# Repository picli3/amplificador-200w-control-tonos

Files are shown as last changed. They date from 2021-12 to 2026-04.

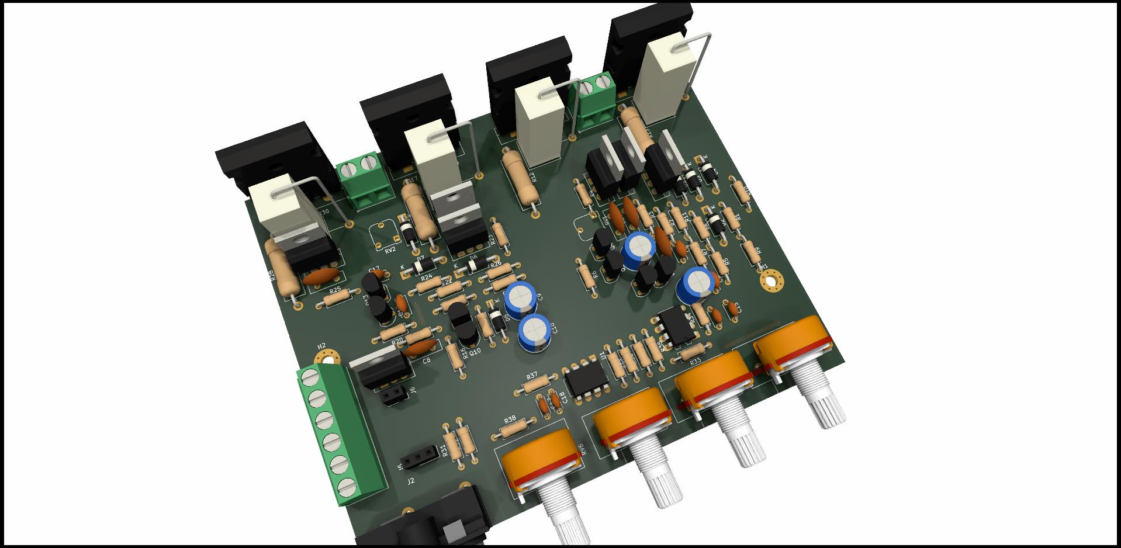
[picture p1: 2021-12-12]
doc/amplificador_200w_estereo.jpg

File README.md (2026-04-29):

# amplificador-200w-control-tonos

Diseño de amplificador de audio con control de tonos, pensado para integrar etapa de potencia y acondicionamiento de señal en una sola solución de hardware.

## Qué incluye
- esquemáticos o archivos de diseño en KiCad
- PCB o documentación asociada
- base reutilizable para análisis, fabricación o mejora del proyecto

## Propósito general
Este repositorio busca concentrar el diseño de hardware del proyecto en un formato editable y reutilizable, facilitando pruebas, documentación y futuras iteraciones del circuito.

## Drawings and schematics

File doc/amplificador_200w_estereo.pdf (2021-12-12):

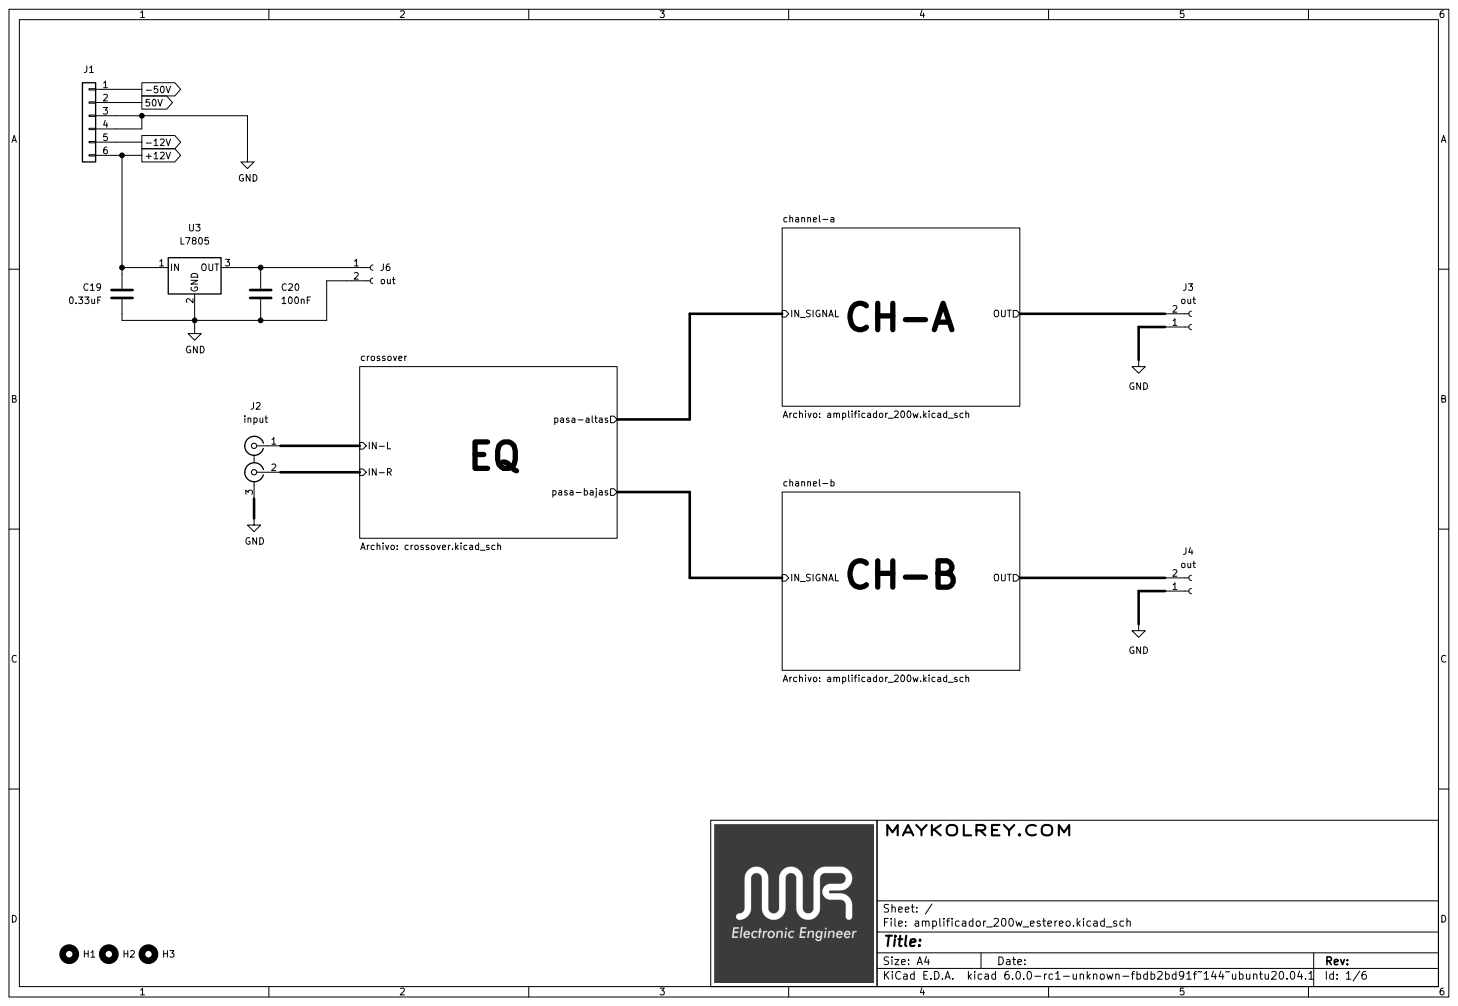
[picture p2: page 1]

File: amplificador_200w_estereo.kicad_sch Sheet: / MAYKOLREY.COM

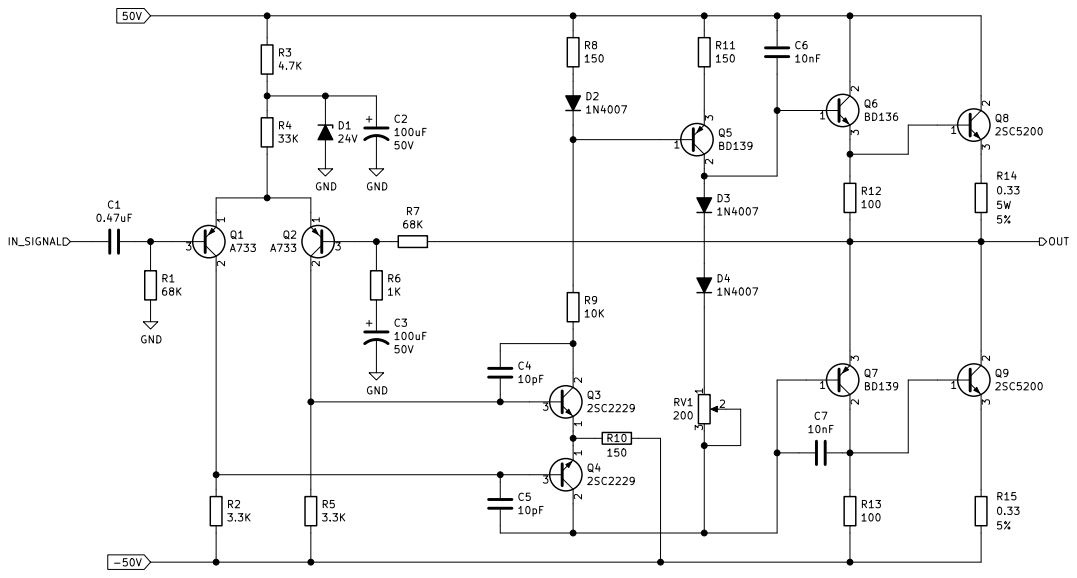
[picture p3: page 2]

File: amplificador_200w.kicad_sch Sheet: /channel-a/ https://maykolrey.com

Id: 2/6 Title: Amplificador Zener 100W

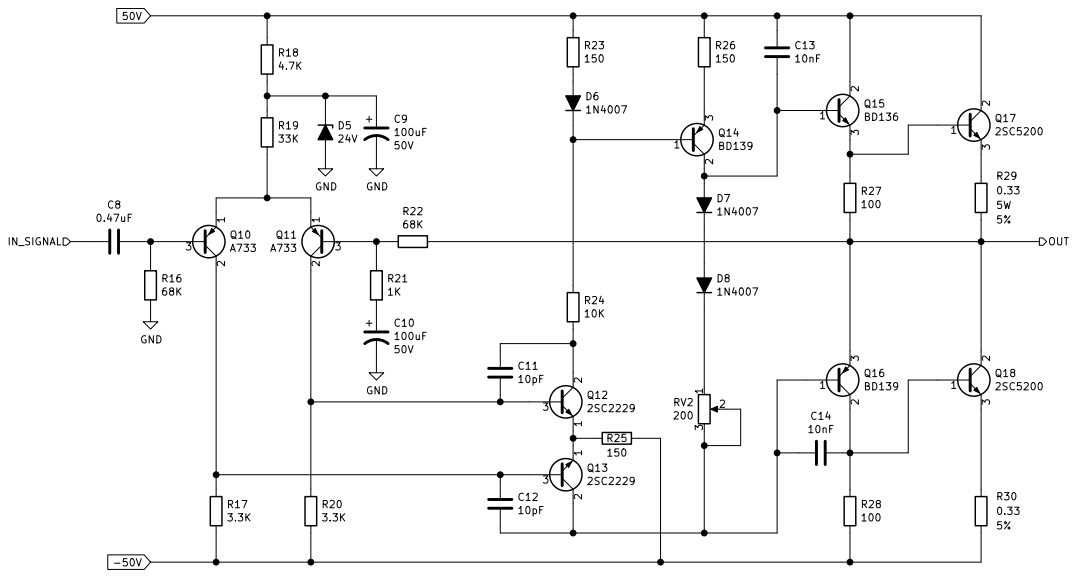
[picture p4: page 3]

File: amplificador_200w.kicad_sch Sheet: /channel-b/ https://maykolrey.com

Id: 3/6 Title: Amplificador Zener 100W

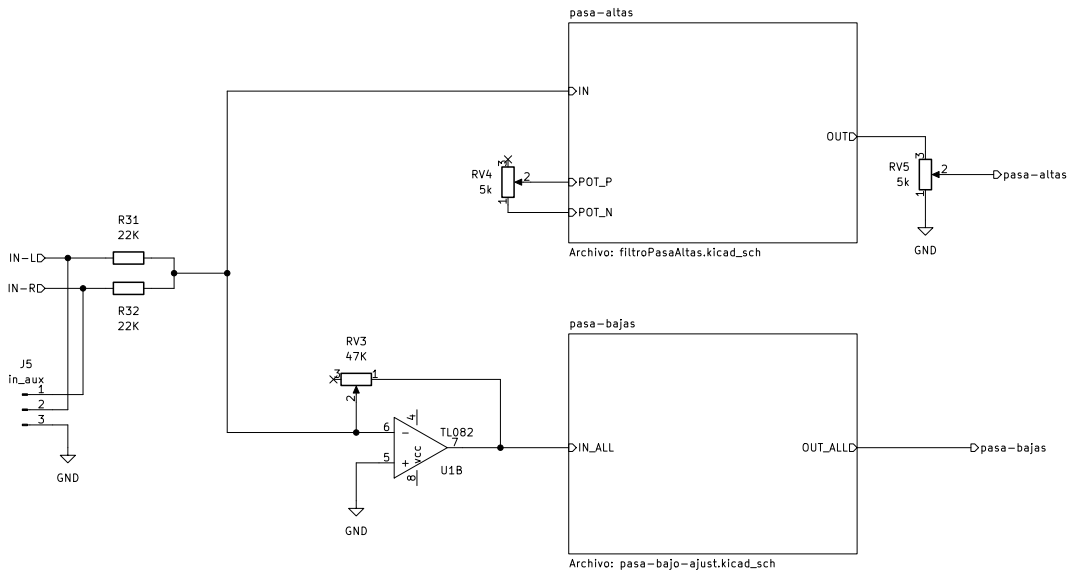
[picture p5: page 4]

pasa-altas Archivo: filtroPasaAltas.kicad_sch
Archivo: pasa-bajo-ajust.kicad_sch POT_N

File: crossover.kicad_sch Sheet: /crossover/ MAYKOLREY.COM

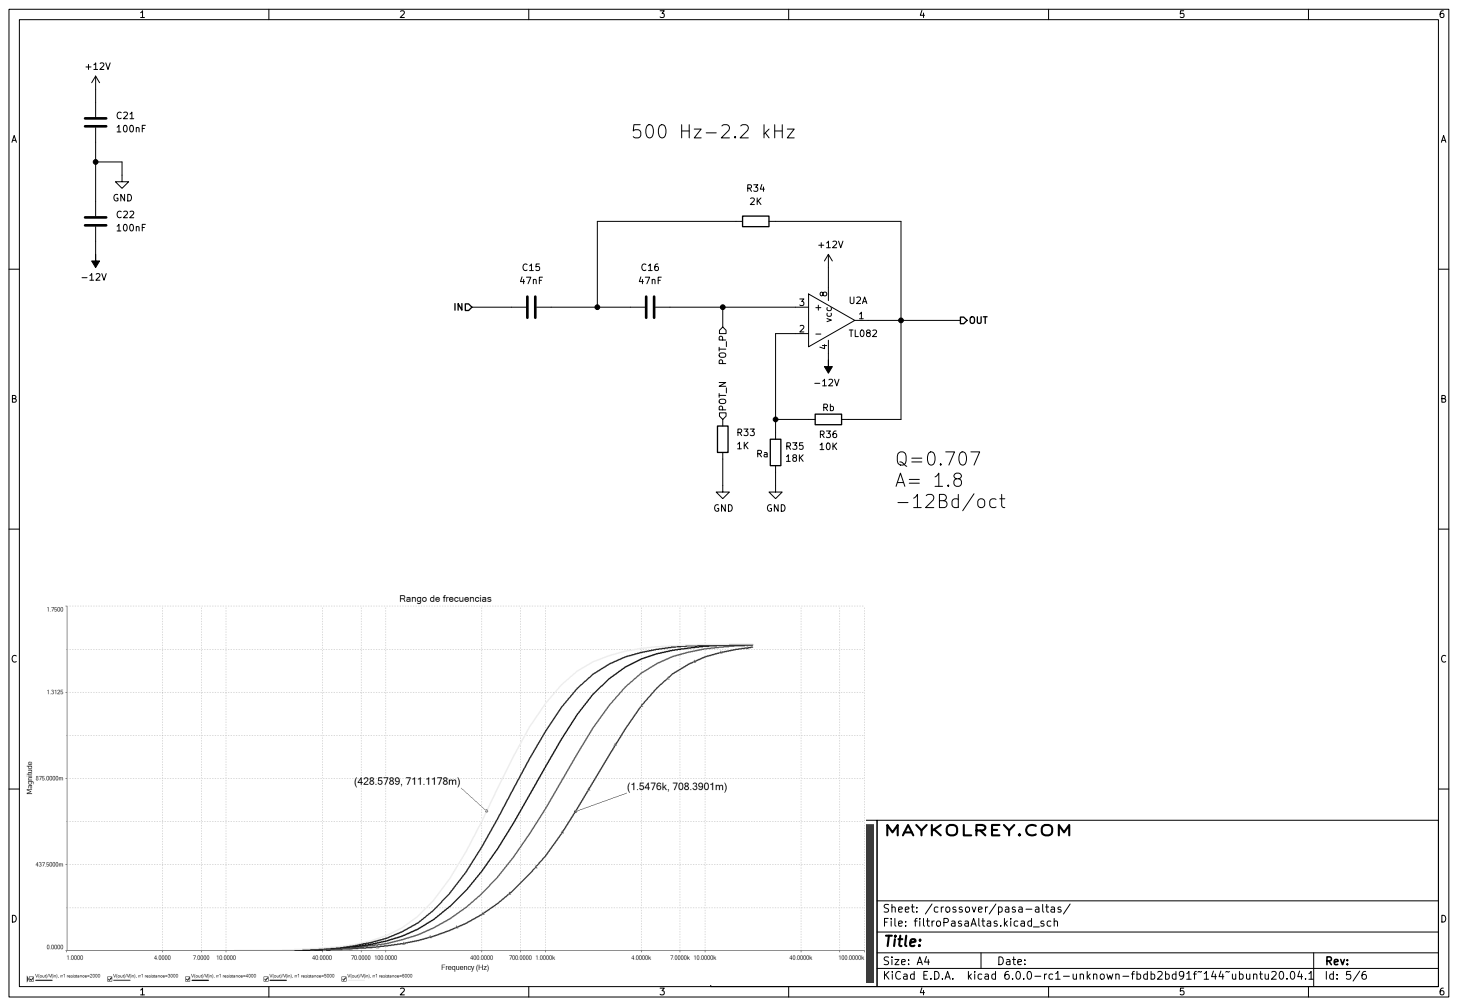
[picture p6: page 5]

Sheet: /crossover/pasa-altas/
File: filtroPasaAltas.kicad_sch
Id: 5/6 Title:

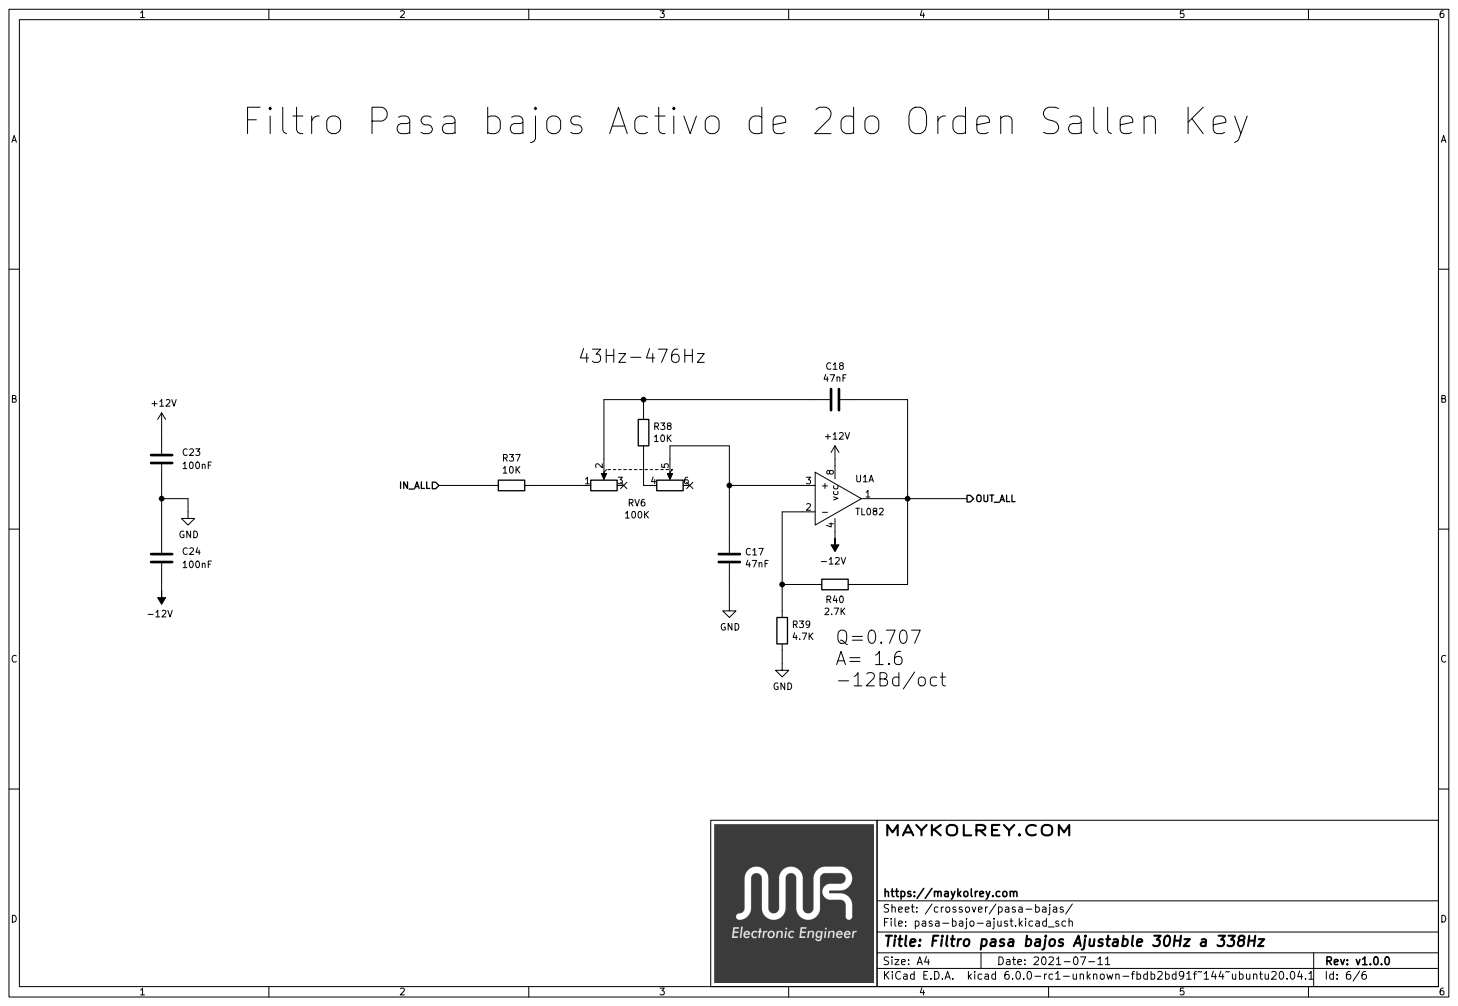
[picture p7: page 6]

Filtro Pasa bajos Activo de 2do Orden Sallen Key

https://maykolrey.com
Sheet: /crossover/pasa-bajas/
File: pasa-bajo-ajust.kicad_sch
Id: 6/6 Title: Filtro pasa bajos Ajustable 30Hz a 338Hz

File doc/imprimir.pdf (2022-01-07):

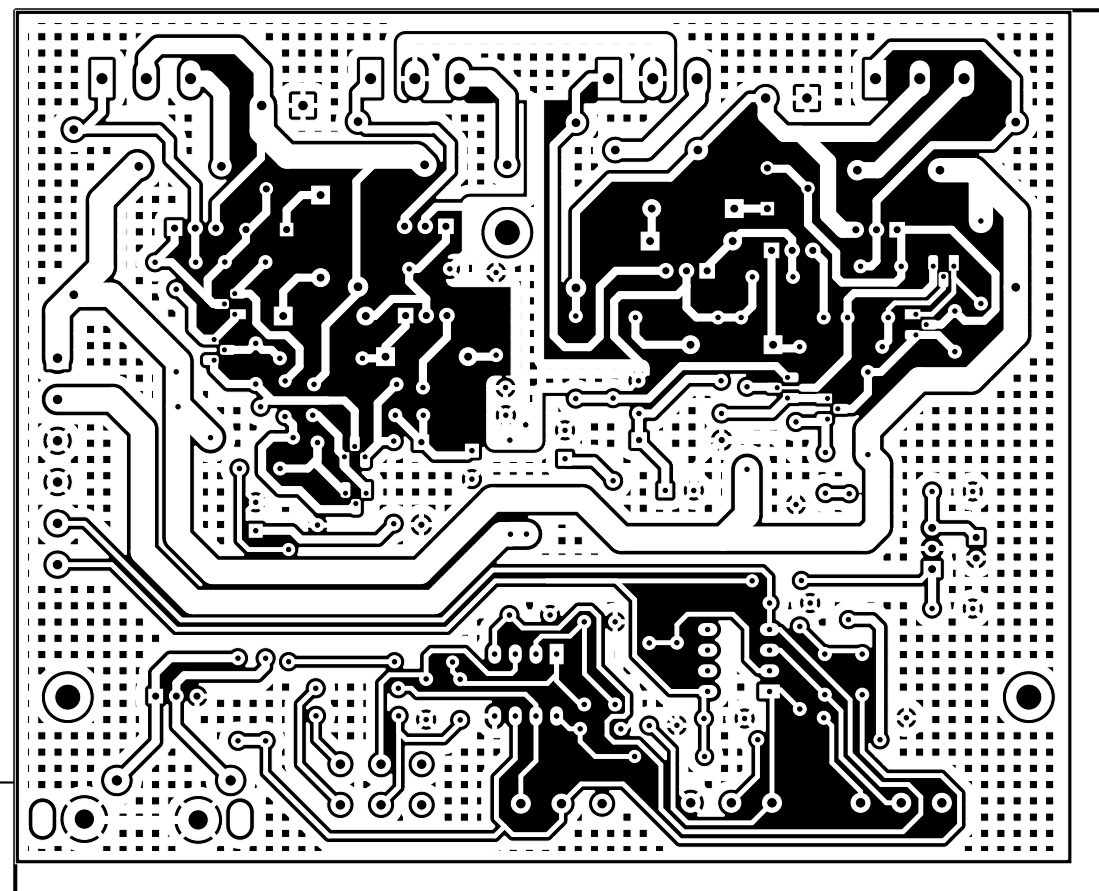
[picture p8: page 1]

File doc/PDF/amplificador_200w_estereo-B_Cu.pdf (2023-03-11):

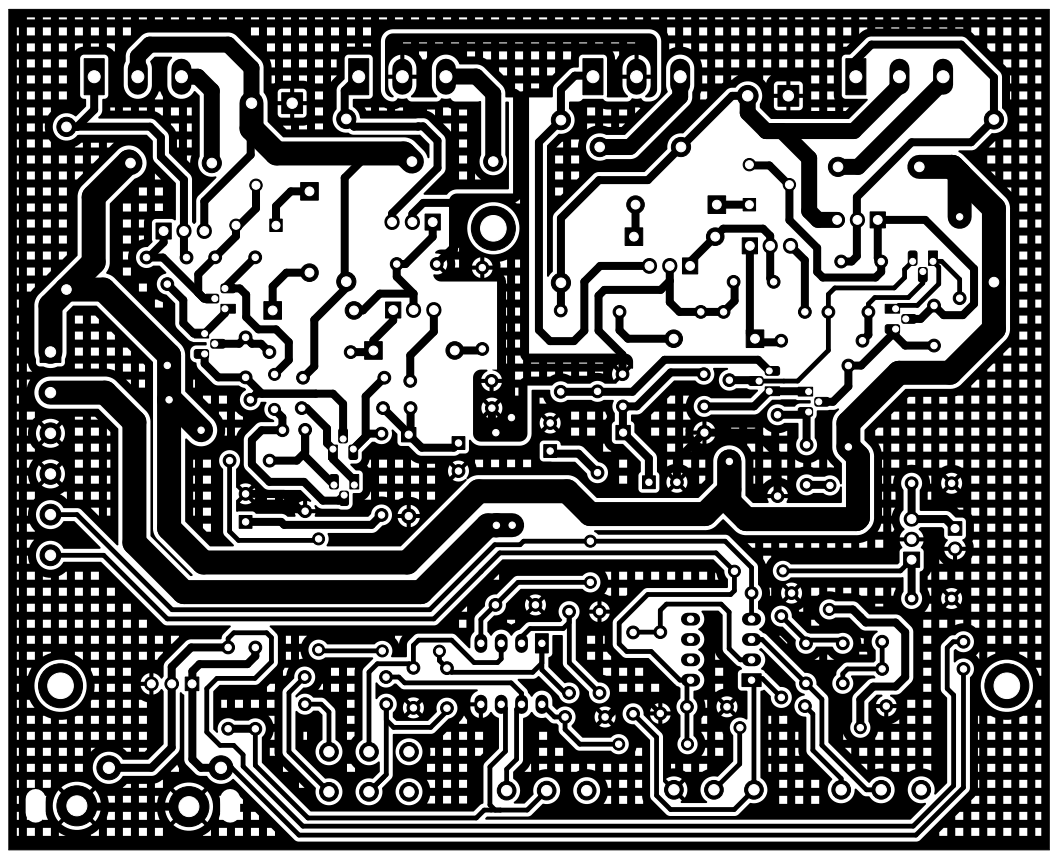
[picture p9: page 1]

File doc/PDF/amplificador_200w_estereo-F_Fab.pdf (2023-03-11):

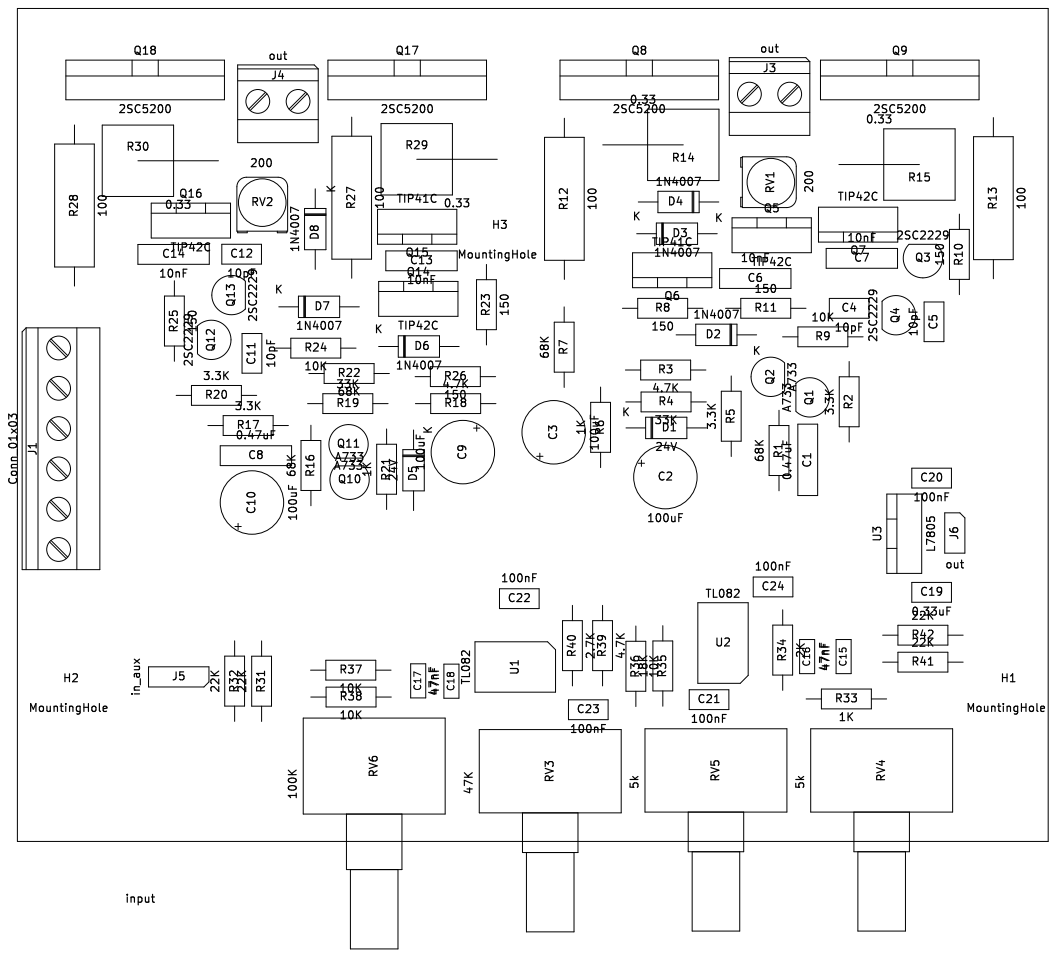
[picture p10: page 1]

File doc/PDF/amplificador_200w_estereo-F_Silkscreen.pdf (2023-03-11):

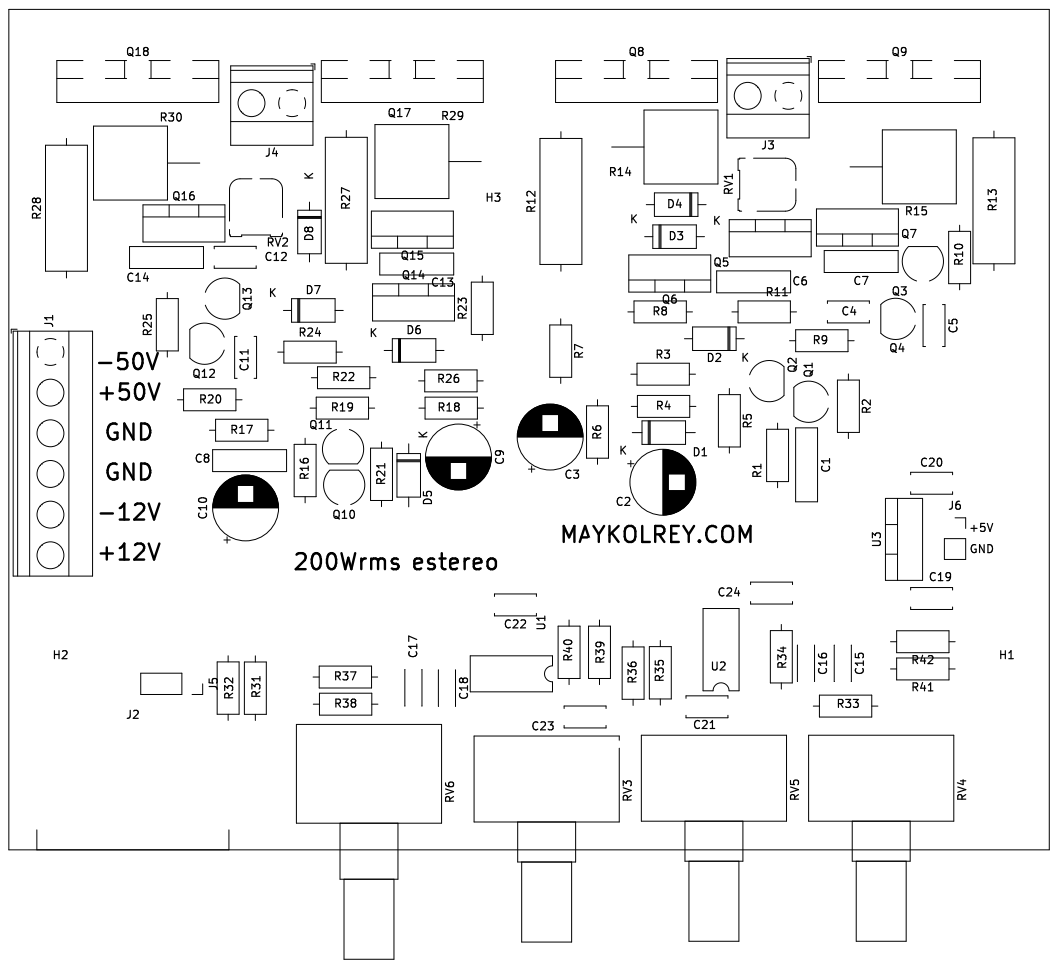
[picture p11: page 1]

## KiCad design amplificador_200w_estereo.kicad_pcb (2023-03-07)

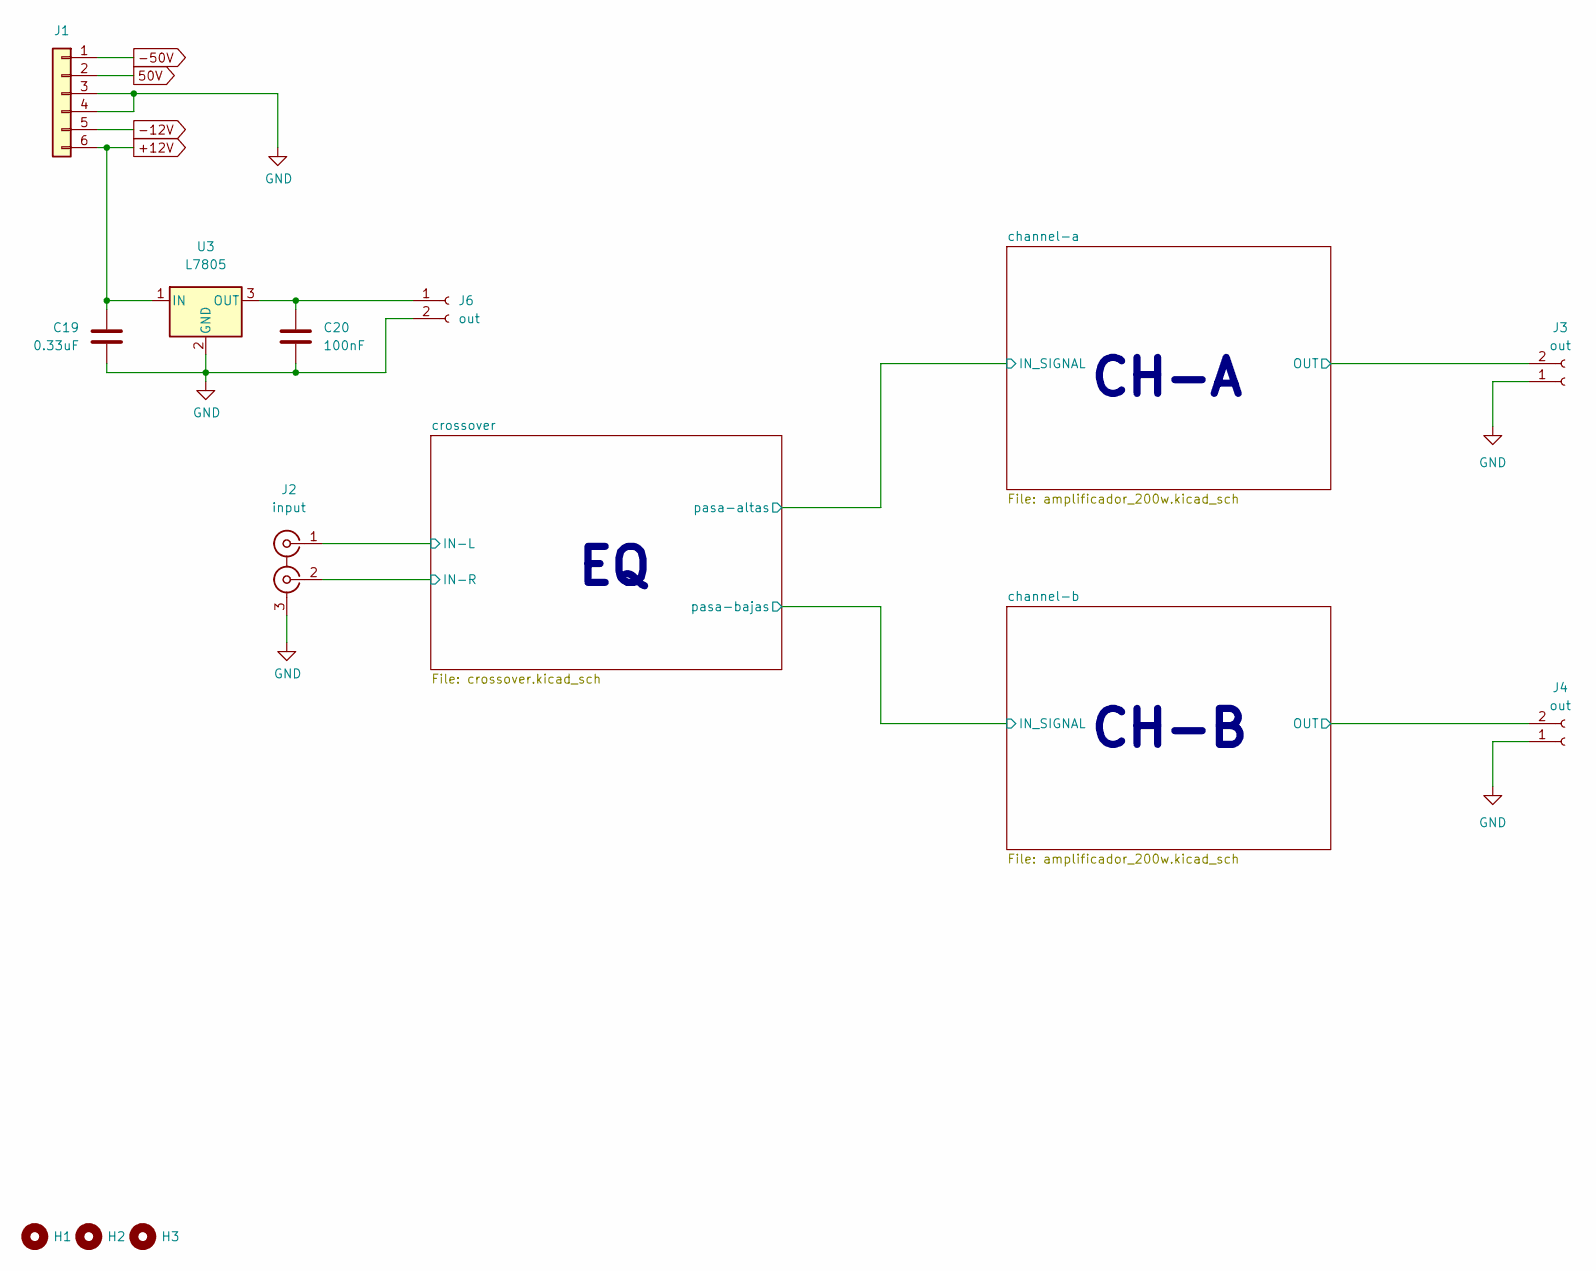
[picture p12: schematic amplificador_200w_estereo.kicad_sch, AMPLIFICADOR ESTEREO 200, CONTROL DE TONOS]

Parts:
C19: 0.33uF; C_Disc_D5.0mm_W2.5mm_P5.00mm
C20: 100nF; C_Disc_D5.0mm_W2.5mm_P5.00mm
H1, H2, H3: MountingHole; MountingHole_3.2mm_M3_ISO14580_Pad
J1: Conn_01x03; TerminalBlock_Phoenix_MKDS-1,5-6-5.08_1x06_P5.08mm_Horizont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
J2: input; CUI_RCJ-21XX
J3, J4, J6: out; TerminalBlock_Phoenix_MKDS-1,5-2-5.08_1x02_P5.08mm_Horizont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
U3: L7805; TO-220-3_Vertical

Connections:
50V: J1.2; also elsewhere on the board
+12V: C19.1, J1.6, U3.1 (IN); also elsewhere on the board
-12V: J1.5; also elsewhere on the board
-50V: J1.1; also elsewhere on the board
/channel-b/OUT: J4.2; also elsewhere on the board
GND: C19.2, C20.2, J1.3, J1.4, J2.3 (EXT), J3.1, J4.1, J6.2, U3.2 (GND); also elsewhere on the board
unnamed 34: C20.1, J6.1, U3.3 (OUT); also elsewhere on the board

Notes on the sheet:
CH-B
CH-A

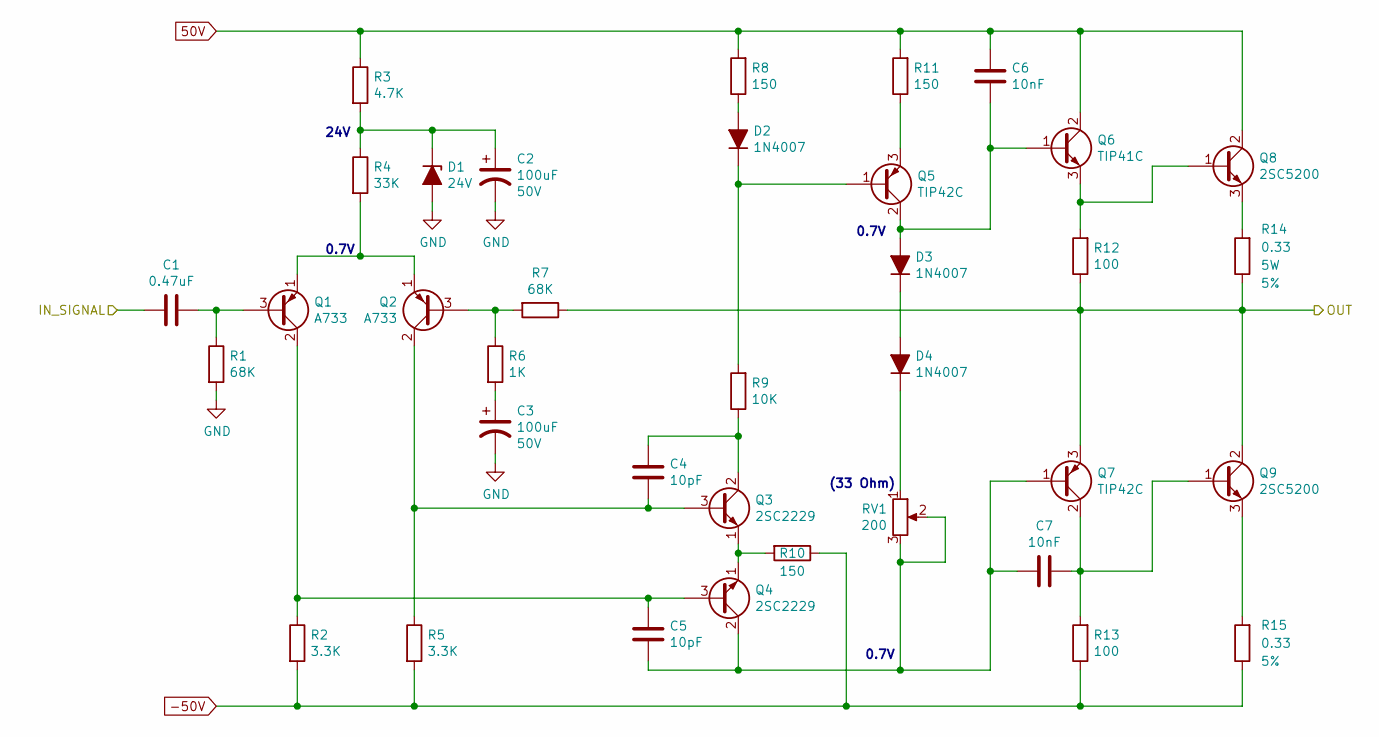
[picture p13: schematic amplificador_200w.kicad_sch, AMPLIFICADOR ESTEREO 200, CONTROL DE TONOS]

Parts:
C1: 0.47uF; C_Disc_D9.0mm_W2.5mm_P5.00mm
C2, C3: 100uF; CP_Radial_D8.0mm_P3.50mm
C4, C5: 10pF; C_Disc_D5.0mm_W2.5mm_P5.00mm
C6, C7: 10nF; C_Disc_D9.0mm_W2.5mm_P5.00mm
D1: 24V; D_A-405_P10.16mm_Horizontal
D2, D3, D4: 1N4007; D_DO-41_SOD81_P10.16mm_Horizontal
Q1, Q2: A733; TO-92L_HandSolder; Mfg Part # KSA733CGBU
Q3, Q4: 2SC2229; TO-92L_HandSolder
Q5, Q7: TIP42C; TO-220-3_Vertical
Q6: TIP41C; TO-220-3_Vertical
Q8, Q9: 2SC5200; TO-264-3_Vertical
R1, R7: 68K; R_Axial_DIN0207_L6.3mm_D2.5mm_P10.16mm_Horizontal
R2, R5: 3.3K; R_Axial_DIN0207_L6.3mm_D2.5mm_P10.16mm_Horizontal
R3: 4.7K; R_Axial_DIN0207_L6.3mm_D2.5mm_P10.16mm_Horizontal
R4: 33K; R_Axial_DIN0207_L6.3mm_D2.5mm_P10.16mm_Horizontal
R6: 1K; R_Axial_DIN0207_L6.3mm_D2.5mm_P10.16mm_Horizontal
R8, R10, R11: 150; R_Axial_DIN0207_L6.3mm_D2.5mm_P10.16mm_Horizontal
R9: 10K; R_Axial_DIN0207_L6.3mm_D2.5mm_P10.16mm_Horizontal
R12, R13: 100; R_Axial_DIN0516_L15.5mm_D5.0mm_P20.32mm_Horizontal
R14, R15: 0.33; R_Axial_Power_L25.0mm_W9.0mm_P10.16mm_Vertical
RV1: 200; Potentiometer_Runtron_RM-065_Vertical

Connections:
50V: C6.2, Q6.2 (C), Q8.2 (C), R3.1, R8.2, R11.2; also elsewhere on the board
-50V: R2.2, R5.2, R10.1, R13.1, R15.1; also elsewhere on the board
/channel-a/IN_SIGNAL: C1.2; also elsewhere on the board
/channel-a/OUT: Q7.3 (E), Q9.2 (C), R7.1, R12.1, R14.1; also elsewhere on the board
GND: C2.2, C3.2, D1.2 (A), R1.2; also elsewhere on the board
unnamed: C1.1, Q1.3 (B), R1.1
unnamed: C2.1, D1.1 (K), R3.2, R4.1
unnamed: C3.1, R6.2
unnamed: C4.1, Q2.2 (C), Q3.3 (B), R5.1
unnamed: C4.2, Q3.2 (C), R9.1
unnamed: C5.1, C7.1, Q4.2 (C), Q7.1 (B), RV1.2, RV1.3
unnamed: C5.2, Q1.2 (C), Q4.3 (B), R2.1
unnamed: C6.1, D3.2 (A), Q5.2 (C), Q6.1 (B)
unnamed: C7.2, Q7.2 (C), Q9.1 (B), R13.2
unnamed: D2.1 (K), Q5.1 (B), R9.2
unnamed: D2.2 (A), R8.1
unnamed: D3.1 (K), D4.2 (A)
unnamed: D4.1 (K), RV1.1
unnamed: Q1.1 (E), Q2.1 (E), R4.2
unnamed: Q2.3 (B), R6.1, R7.2
unnamed: Q3.1 (E), Q4.1 (E), R10.2
unnamed: Q5.3 (E), R11.1
unnamed: Q6.3 (E), Q8.1 (B), R12.2
unnamed: Q8.3 (E), R14.2
unnamed: Q9.3 (E), R15.2

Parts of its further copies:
C8: 0.47uF; C_Disc_D9.0mm_W2.5mm_P5.00mm
C9, C10: 100uF; CP_Radial_D8.0mm_P3.50mm
C11, C12: 10pF; C_Disc_D5.0mm_W2.5mm_P5.00mm
C13, C14: 10nF; C_Disc_D9.0mm_W2.5mm_P5.00mm
D5: 24V; D_A-405_P10.16mm_Horizontal
D6, D7, D8: 1N4007; D_DO-41_SOD81_P10.16mm_Horizontal
Q10, Q11: A733; TO-92L_HandSolder; Mfg Part # KSA733CGBU
Q12, Q13: 2SC2229; TO-92L_HandSolder
Q14, Q16: TIP42C; TO-220-3_Vertical
Q15: TIP41C; TO-220-3_Vertical
Q17, Q18: 2SC5200; TO-264-3_Vertical
R16, R22: 68K; R_Axial_DIN0207_L6.3mm_D2.5mm_P10.16mm_Horizontal
R17, R20: 3.3K; R_Axial_DIN0207_L6.3mm_D2.5mm_P10.16mm_Horizontal
R18: 4.7K; R_Axial_DIN0207_L6.3mm_D2.5mm_P10.16mm_Horizontal
R19: 33K; R_Axial_DIN0207_L6.3mm_D2.5mm_P10.16mm_Horizontal
R21: 1K; R_Axial_DIN0207_L6.3mm_D2.5mm_P10.16mm_Horizontal
R23, R25, R26: 150; R_Axial_DIN0207_L6.3mm_D2.5mm_P10.16mm_Horizontal
R24: 10K; R_Axial_DIN0207_L6.3mm_D2.5mm_P10.16mm_Horizontal
R27, R28: 100; R_Axial_DIN0516_L15.5mm_D5.0mm_P20.32mm_Horizontal
R29, R30: 0.33; R_Axial_Power_L25.0mm_W9.0mm_P10.16mm_Vertical
RV2: 200; Potentiometer_Runtron_RM-065_Vertical

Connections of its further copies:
50V: C13.2, Q15.2 (C), Q17.2 (C), R18.1, R23.2, R26.2; also elsewhere on the board
-50V: R17.2, R20.2, R25.1, R28.1, R30.1; also elsewhere on the board
/channel-b/IN_SIGNAL: C8.2; also elsewhere on the board
/channel-b/OUT: Q16.3 (E), Q18.2 (C), R22.1, R27.1, R29.1; also elsewhere on the board
GND: C9.2, C10.2, D5.2 (A), R16.2; also elsewhere on the board
unnamed: C8.1, Q10.3 (B), R16.1
unnamed: C9.1, D5.1 (K), R18.2, R19.1
unnamed: C10.1, R21.2
unnamed: C11.1, Q11.2 (C), Q12.3 (B), R20.1
unnamed: C11.2, Q12.2 (C), R24.1
unnamed: C12.1, C14.1, Q13.2 (C), Q16.1 (B), RV2.2, RV2.3
unnamed: C12.2, Q10.2 (C), Q13.3 (B), R17.1
unnamed: C13.1, D7.2 (A), Q14.2 (C), Q15.1 (B)
unnamed: C14.2, Q16.2 (C), Q18.1 (B), R28.2
unnamed: D6.1 (K), Q14.1 (B), R24.2
unnamed: D6.2 (A), R23.1
unnamed: D7.1 (K), D8.2 (A)
unnamed: D8.1 (K), RV2.1
unnamed: Q10.1 (E), Q11.1 (E), R19.2
unnamed: Q11.3 (B), R21.1, R22.2
unnamed: Q12.1 (E), Q13.1 (E), R25.2
unnamed: Q14.3 (E), R26.1
unnamed: Q15.3 (E), Q17.1 (B), R27.2
unnamed: Q17.3 (E), R29.2
unnamed: Q18.3 (E), R30.2

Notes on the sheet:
0.7V
(33 Ohm)
24V

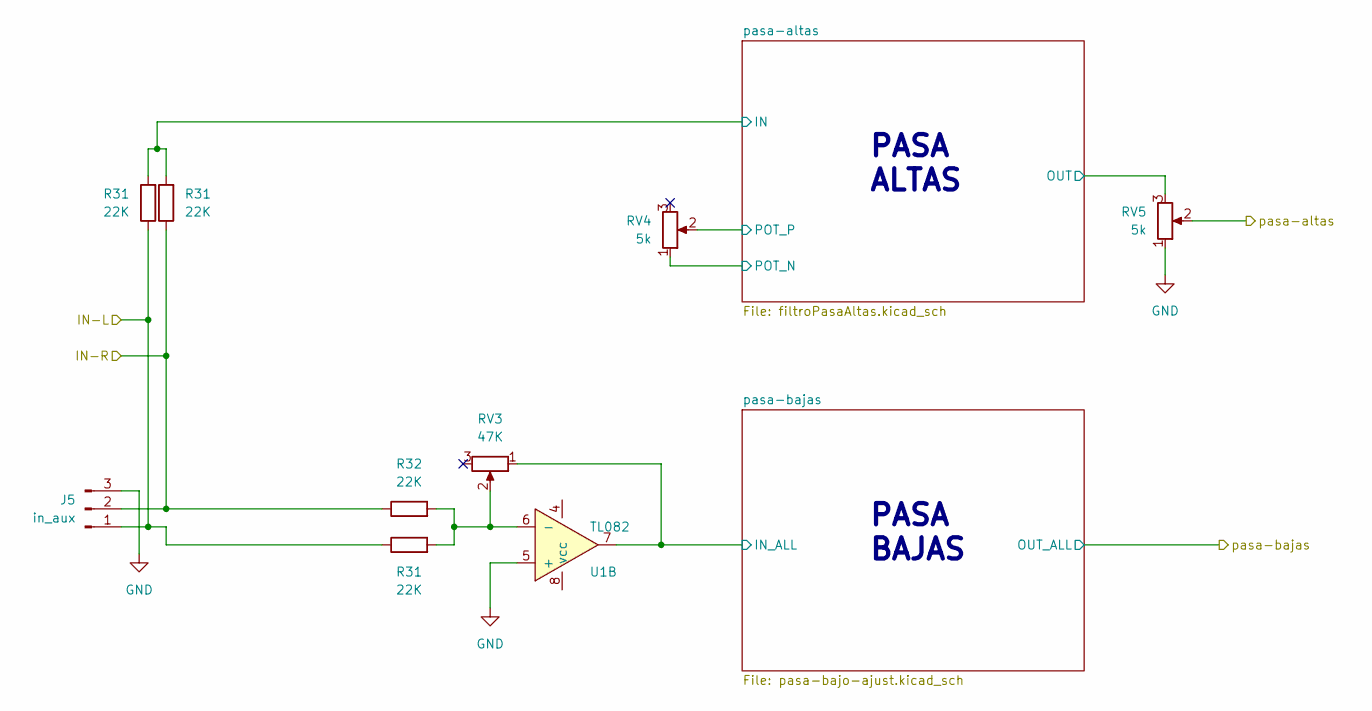
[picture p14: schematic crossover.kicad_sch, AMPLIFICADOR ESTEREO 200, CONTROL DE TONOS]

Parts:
J5: in_aux; PinSocket_1x03_P2.54mm_Vertical
R31, R32: 22K; R_Axial_DIN0207_L6.3mm_D2.5mm_P10.16mm_Horizontal
RV3: 47K; Potentiometer_Alps_RK163_Single_Horizontal
RV4, RV5: 5k; Potentiometer_Alps_RK163_Single_Horizontal
U1: TL082; DIP-8_W7.62mm_LongPads

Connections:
+12V: U1.8 (vcc); also elsewhere on the board
-12V: U1.4; also elsewhere on the board
/channel-a/IN_SIGNAL: RV5.2; also elsewhere on the board
/crossover/pasa-altas/OUT: RV5.3; also elsewhere on the board
/crossover/pasa-altas/POT_N: RV4.1; also elsewhere on the board
/crossover/pasa-altas/POT_P: RV4.2; also elsewhere on the board
/crossover/pasa-bajas/IN_ALL: RV3.1, U1.7; also elsewhere on the board
GND: J5.3, RV5.1, U1.5 (+); also elsewhere on the board

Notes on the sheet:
PASA ALTAS
PASA BAJAS

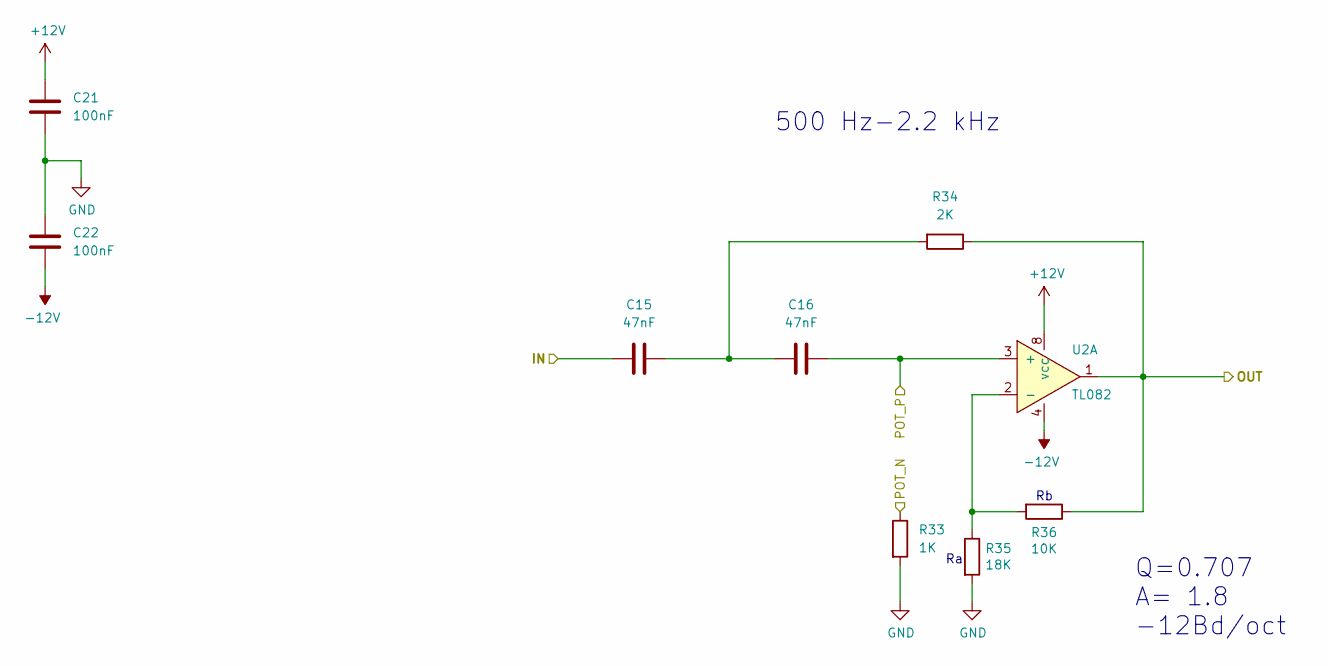
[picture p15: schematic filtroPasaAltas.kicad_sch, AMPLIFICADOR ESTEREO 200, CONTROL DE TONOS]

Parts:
C15, C16: 47nF; C_Disc_D4.3mm_W1.9mm_P5.00mm
C21, C22: 100nF; C_Disc_D5.0mm_W2.5mm_P5.00mm
R33: 1K; R_Axial_DIN0207_L6.3mm_D2.5mm_P10.16mm_Horizontal
R34: 2K; R_Axial_DIN0207_L6.3mm_D2.5mm_P10.16mm_Horizontal
R35: 18K; R_Axial_DIN0207_L6.3mm_D2.5mm_P10.16mm_Horizontal
R36: 10K; R_Axial_DIN0207_L6.3mm_D2.5mm_P10.16mm_Horizontal
U2: TL082; DIP-8_W7.62mm_LongPads

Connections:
+12V: C21.1, U2.8 (vcc); also elsewhere on the board
-12V: C22.2, U2.4; also elsewhere on the board
/crossover/pasa-altas/OUT: R34.1, R36.1, U2.1; also elsewhere on the board
/crossover/pasa-altas/POT_N: R33.1; also elsewhere on the board
/crossover/pasa-altas/POT_P: C16.1, U2.3 (+); also elsewhere on the board
GND: C21.2, C22.1, R33.2, R35.2; also elsewhere on the board
unnamed: C15.1, C16.2, R34.2
unnamed: R35.1, R36.2, U2.2 (-)

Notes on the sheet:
Q=0.707 A= 1.8 -12Bd/oct
500 Hz-2.2 kHz

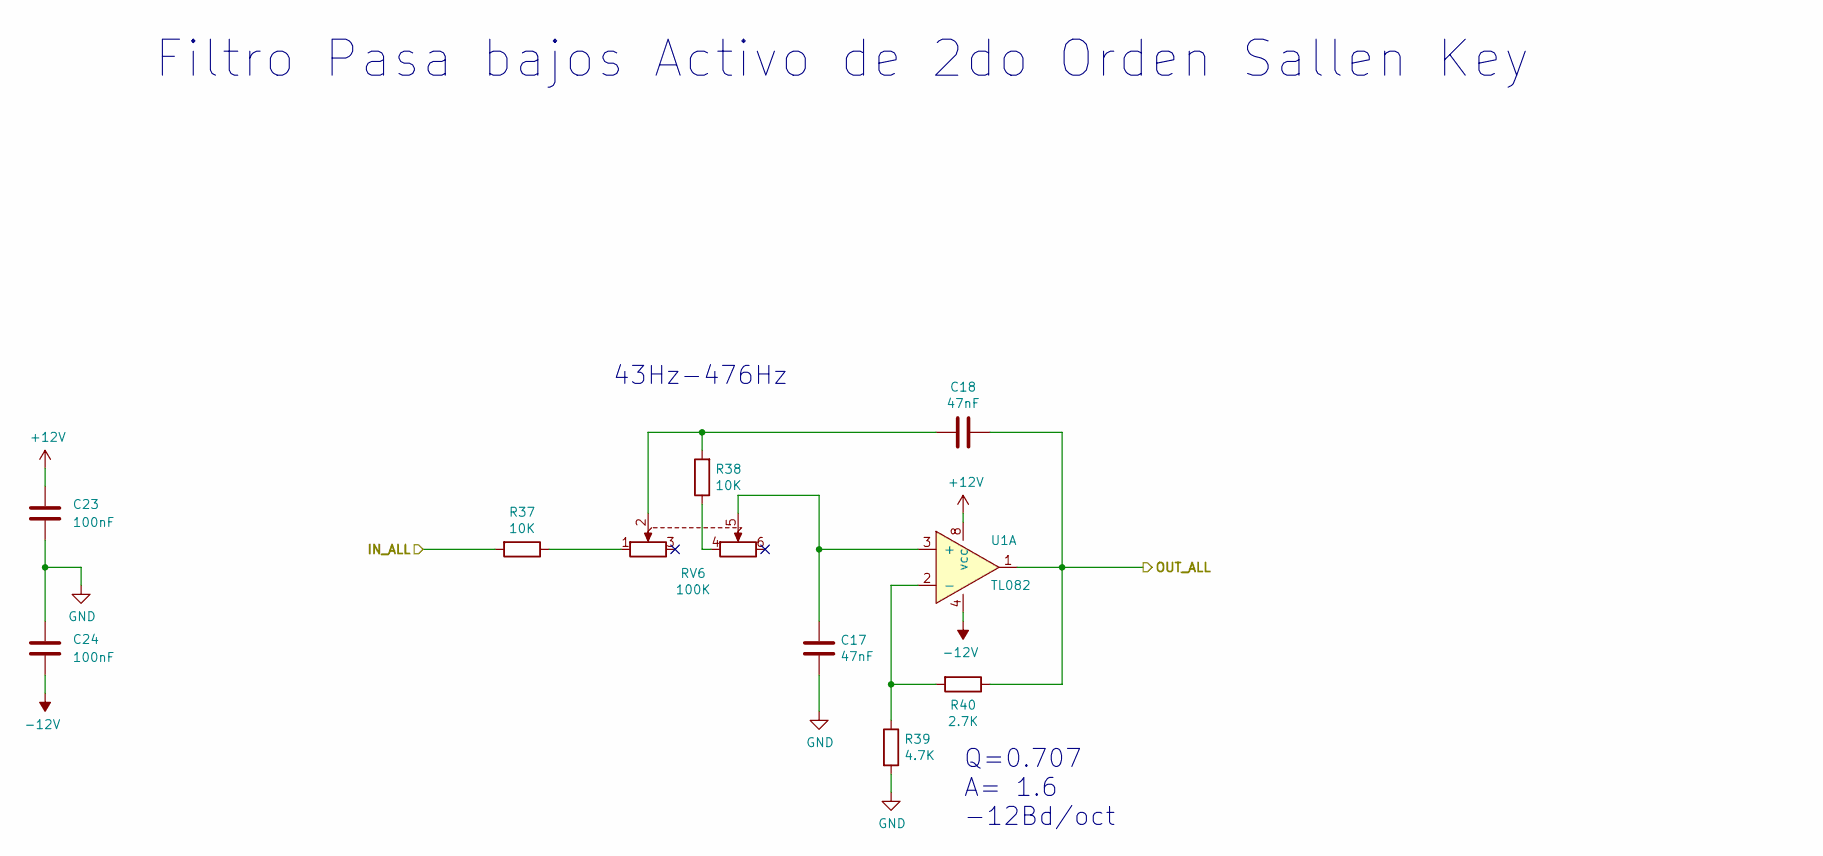
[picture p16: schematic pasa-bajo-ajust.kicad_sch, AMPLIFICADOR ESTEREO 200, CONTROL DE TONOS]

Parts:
C17, C18: 47nF; C_Disc_D4.3mm_W1.9mm_P5.00mm
C23, C24: 100nF; C_Disc_D5.0mm_W2.5mm_P5.00mm
R37, R38: 10K; R_Axial_DIN0207_L6.3mm_D2.5mm_P10.16mm_Horizontal
R39: 4.7K; R_Axial_DIN0207_L6.3mm_D2.5mm_P10.16mm_Horizontal
R40: 2.7K; R_Axial_DIN0207_L6.3mm_D2.5mm_P10.16mm_Horizontal
RV6: 100K; Potentiometer_Alps_RK163_Dual_Horizontal
U1: TL082; DIP-8_W7.62mm_LongPads

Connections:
+12V: C23.1, U1.8 (vcc); also elsewhere on the board
-12V: C24.2, U1.4; also elsewhere on the board
/channel-b/IN_SIGNAL: C18.1, R40.1, U1.1; also elsewhere on the board
/crossover/pasa-bajas/IN_ALL: R37.2; also elsewhere on the board
GND: C17.1, C23.2, C24.1, R39.2; also elsewhere on the board
unnamed: C17.2, RV6.5, U1.3 (+)
unnamed: C18.2, R38.2, RV6.2
unnamed: R37.1, RV6.1
unnamed: R38.1, RV6.4
unnamed: R39.1, R40.2, U1.2 (-)

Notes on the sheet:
Filtro Pasa bajos Activo de 2do Orden Sallen Key
Q=0.707 A= 1.6 -12Bd/oct
43Hz-476Hz

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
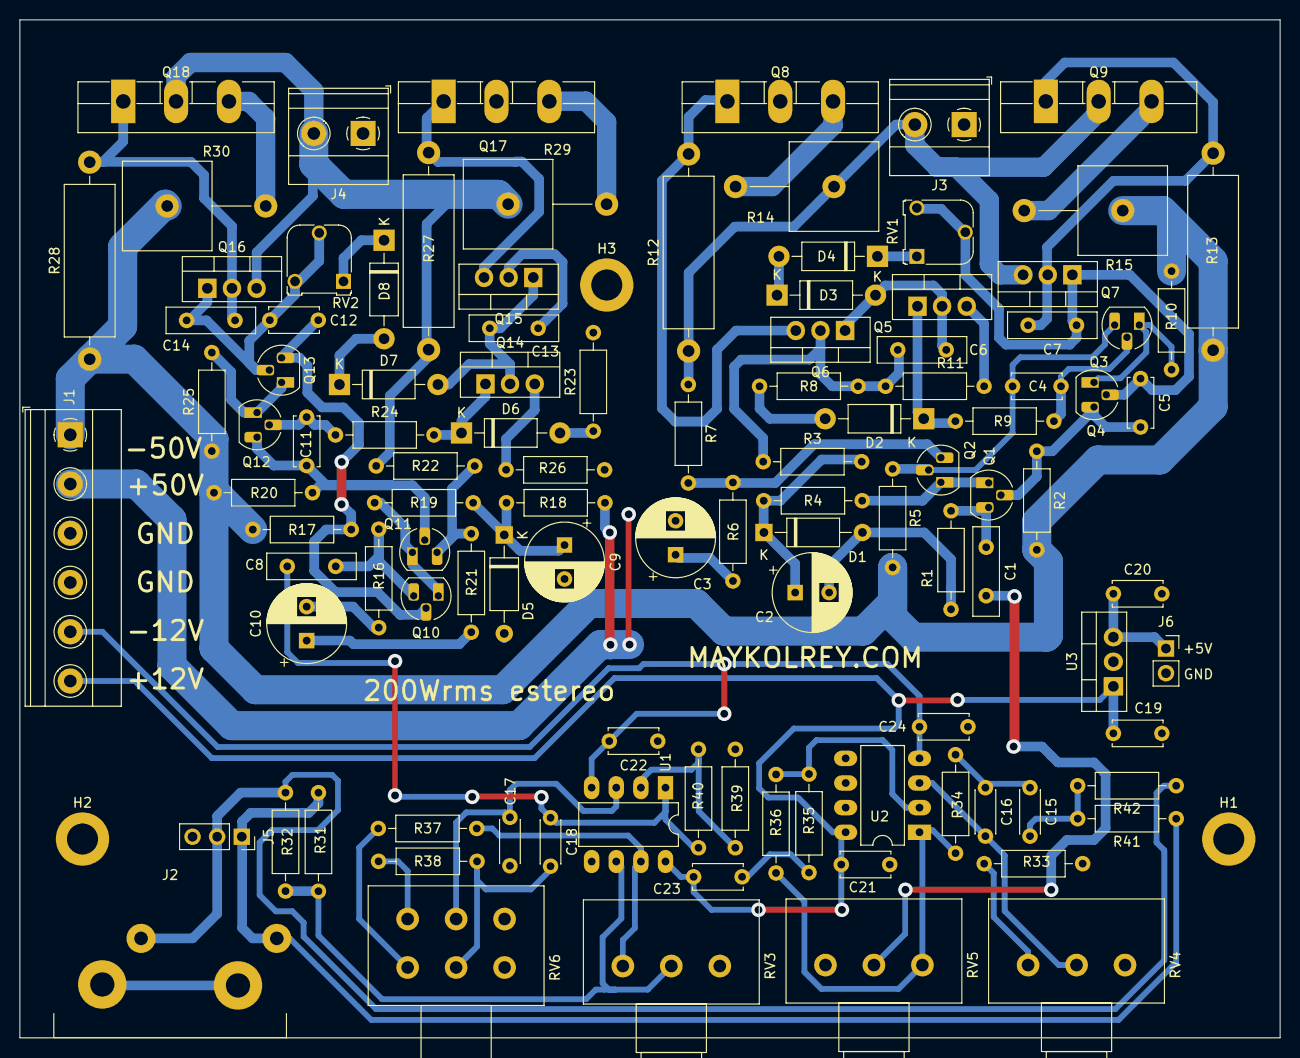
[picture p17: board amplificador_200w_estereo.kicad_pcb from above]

Board: 2 copper layers, 130.0 x 105.0 mm, 110 parts (0 on the bottom side), 65 nets.

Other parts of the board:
J?: out; PinSocket_1x02_P2.54mm_Vertical
J?#2: out; TerminalBlock_Phoenix_MKDS-1,5-2-5.08_1x02_P5.08mm_Horizont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
R31#2, R31#3: 22K; R_Axial_DIN0207_L6.3mm_D2.5mm_P10.16mm_Horizontal

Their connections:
/channel-a/OUT: J?#2.2; also elsewhere on the board
GND: J?.2, J?#2.1; also elsewhere on the board
unnamed 34: J?.1; also elsewhere on the board

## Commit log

2021-12-12 primera fabricacion
    [amplificador_200w.kicad_sch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]
2022-01-07 Separando las altas con resistencias de 22K
    [amplificador_200w.kicad_sch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]
2023-03-07 actualizando a kicad 7
    [amplificador_200w.kicad_sch, amplificador_200w_estereo.kicad_pcb, amplificador_200w_estereo.kicad_sch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]
2023-03-11 agregando archivos pdf del pcb
